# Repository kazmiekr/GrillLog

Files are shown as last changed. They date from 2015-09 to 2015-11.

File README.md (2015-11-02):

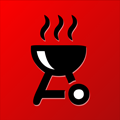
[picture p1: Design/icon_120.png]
 
#GrillLog

This is a project that uses an Arduino UNO to monitor two temperature probes used for a BBQ smoker setup. One probe for food and another for the internal grill temp.  The temperature data is collected by the Arduino, then sent to a proxy server via the SparkFun wifi shield, which is based on the ESP8266.  The proxy server then forwards the temperature data to parse.com as parse.com required HTTPS and the ESP8266 doesn't.  Before the data is saved on Parse, a `beforeSave` trigger fires, and if the temp goes over a certain threshold, it will send a push notification to any subscribed clients.  There is an iOS project in here that allows for simple reading of the parse.com data.

# Project Writeup

View a full writeup of the project at http://www.universalmind.com/smoking-meat-with-the-internet-of-things/

##Parts
* Breadboard 
* Misc Jumper wires
* [Arduino Uno R3](http://www.amazon.com/Arduino-Ultimate-Starter-page-Instruction/dp/B00BT0NDB8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)
* [Sparkfun Wifi Shield](https://www.sparkfun.com/products/13287)
* [Maverick ET732 Smoker Probe](http://www.amazon.com/gp/product/B006XLWL7K?psc=1&redirect=true&ref_=oh_aui_detailpage_o04_s00)
* Generic Food Probe - ( I’m using one from [this](http://www.amazon.com/Oregon-Scientific-AW129-Wireless-Thermometer/dp/B0006G2WYK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))
* 1X 10K Trimpot
* 1X 16x2 LCD Module With Presoldered pinheaders ( Using the one from [this](http://www.amazon.com/gp/product/B00HI0RYJK?psc=1&redirect=true&ref_=oh_aui_detailpage_o06_s00) )
* 1X 220K resistor
* 1X 1M resistor
* 2X [2.5mm jacks](http://www.amazon.com/gp/product/B00AKWR59M?psc=1&redirect=true&ref_=oh_aui_detailpage_o06_s00) soldered to wires

##Diagram
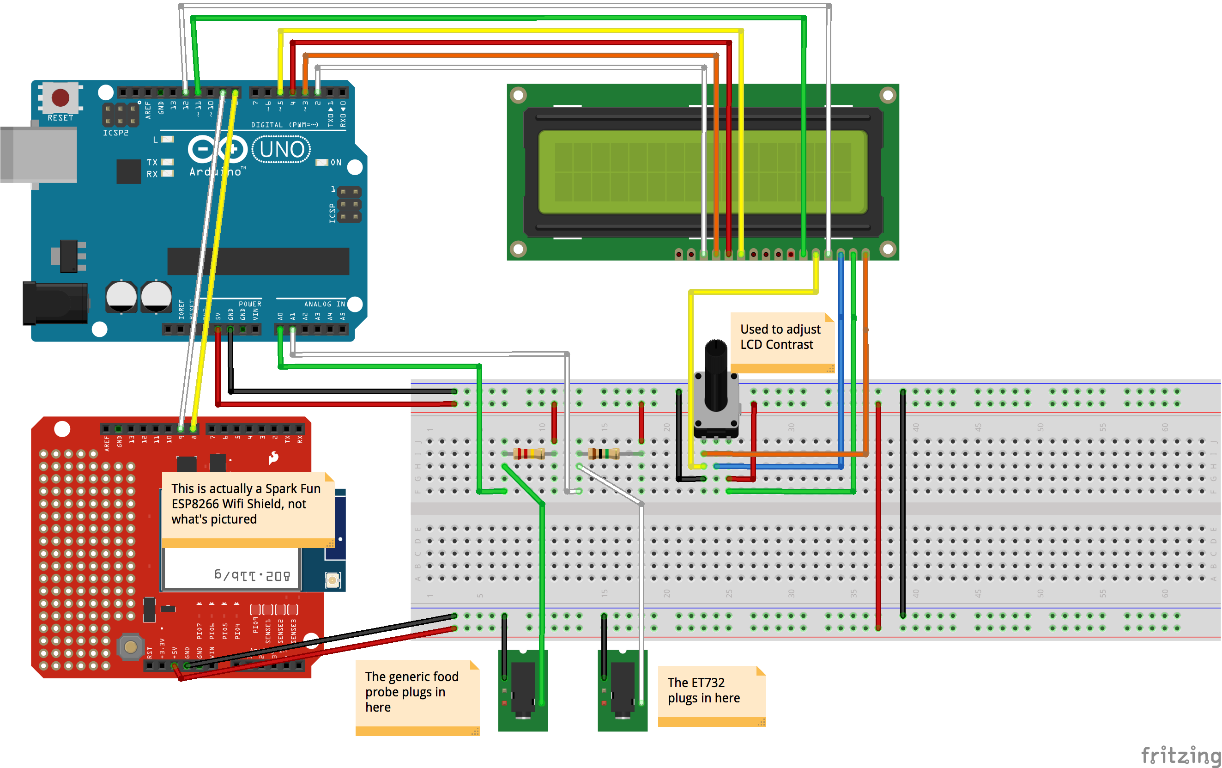
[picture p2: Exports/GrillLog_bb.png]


##Pictures
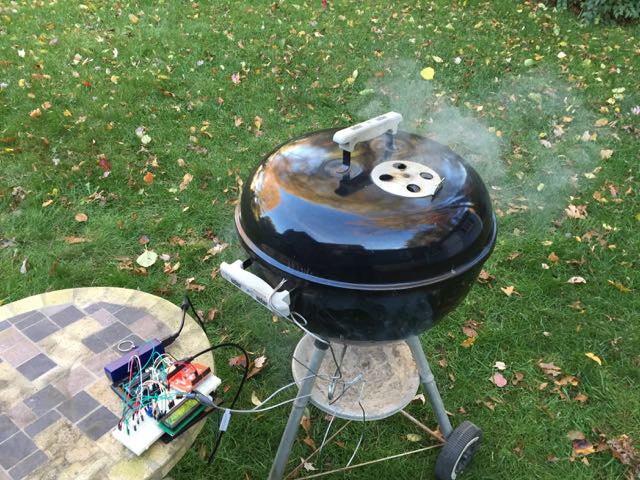
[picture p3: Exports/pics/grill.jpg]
Grill

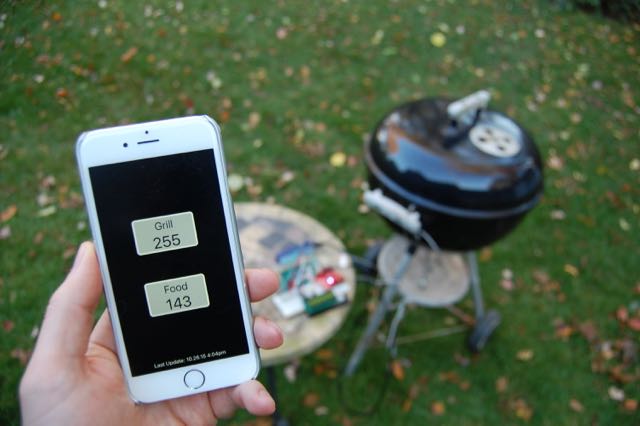
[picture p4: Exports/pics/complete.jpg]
Complete


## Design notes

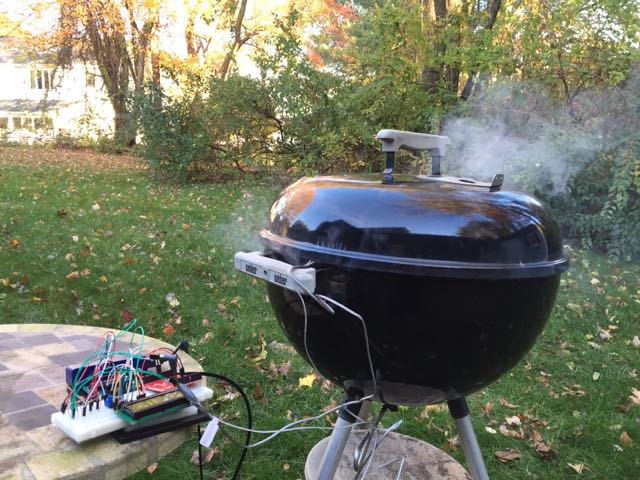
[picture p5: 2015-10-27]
Exports/pics/grill2.jpg

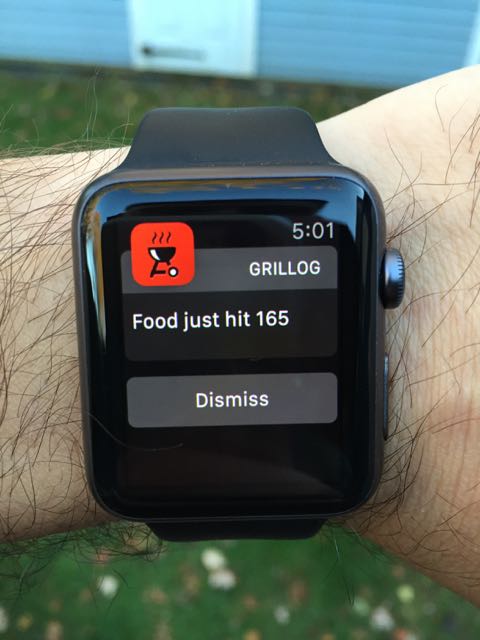
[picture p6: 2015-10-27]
Exports/pics/watch.jpg

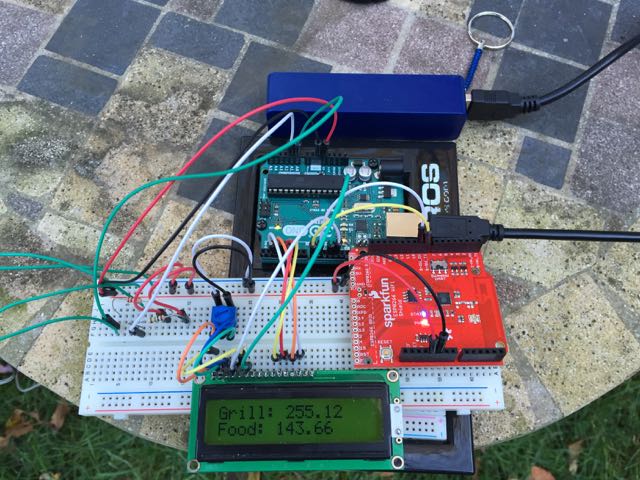
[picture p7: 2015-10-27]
Exports/pics/circuit.jpg

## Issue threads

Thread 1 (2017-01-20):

What is the board the 2.5mm are soldered to?

daleyjem, 2017-01-20:
Maybe I'm missing something, but what is the board that the 2.5mm jacks are soldered to? I think that's key as to why I'm getting all zeros by putting the jack straight into the breadboard.

kazmiekr, 2017-01-24:
Hey Jeremy, the 2.5mm jacks are just soldered to wires and the wires are placed into the breadboard. If you aren't getting any values I'd double check connection points and then maybe check it with a multimeter or something to see if the jack is working. Hope that helps! Let me know if you have any other questions! 🍖

daleyjem, 2017-01-24:
I only see 2 wires though... do you not connect the back terminal of the jack to anything?

kazmiekr, 2017-01-25:
I only use two of the 3 connections, I'm not really sure if that's the best approach or not, but that's how I got it to read values.  It was just a bit of trial an error to figure out which connections worked. Hope that helps!

daleyjem, 2017-02-02:
Ok. Which connections did you use, because I bought the exact same ones you used. The back and left? The left and right?

kazmiekr, 2017-02-06:
Back and the left (see picture), I need to make a better connection on these though because the wires constantly break off and I have to re-solder them, just fyi

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

Closed 2017-01-24.

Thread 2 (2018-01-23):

Readings off

clomas, 2018-01-23:
Hello,

I'm not sure if this is the best way to get in touch but I've attempted to use the source code. I'm using an ET-733 probe and a 1M ohm resistor but my readings are off by a bit. In boiling water my probe reads 184F and in water full of ice cubes it reads 44F. Is there anything I could be doing incorrectly? I'm new to programming for electronics, so apologies if it's something obvious.

Thanks
Clint

kazmiekr, 2018-01-31:
Hey Clint! The calculations I used to convert the resistance to temperature aren't an exact thing unfortunately, I had to mess with the numbers a bit for my specific setup. You can read a bit about what I did on my medium post at https://medium.com/@kazmiekr/smoking-meat-with-the-internet-of-things-b047ecda94a0 or you can just try to mess with the beta coefficients in https://github.com/kazmiekr/GrillLog/blob/master/Arduino/GrillLog/GrillLog.ino#L34 . Not sure if that'll help you or not, but maybe it'll get you in the right direction. My temperatures were never really exact, they fluctuated a bit, but were close enough for me. Anytime the meat got close, I'd double check it with a different meat therm.

clomas, 2018-01-31:
Thanks, I'll give it a go. There a a lot of code examples for the ET73 thermometers online, a lot of people recommend them over the thermometers we're using. Might end up trying them. Thanks again mate.

kazmiekr, 2018-02-02:
Clint, let me know what you end up doing, I'd love to hear how people are actually using this code for things. 🍖 🔥

Closed 2018-01-31.

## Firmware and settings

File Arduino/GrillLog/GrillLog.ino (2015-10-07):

/************************************************************
GrillLog
Kevin Kazmierczak

This sketch will read temperature data from two probes using 
A0 and A1 and will sent that data up to a proxy server using an 
ESP8266 via serial commands. The current temperatures are also 
displayed on a 2 line LCD.

************************************************************/

#include <SoftwareSerial.h>
#include <LiquidCrystal.h>

// External lib config
LiquidCrystal lcd(12, 11, 5, 4, 3, 2);
SoftwareSerial esp8266(8,9);

// Generic config
#define TEMP_READ_DELAY 10000 // 10 seconds between temp reading
#define BAUD_RATE 9600 // Baudrate for serial monitor and ESP

// Proxy Server configs
const char destServer[] = "192.168.1.9";
const uint16_t destPort = 8050;
const String postEndpoint = "/temp";

// Temperature Probes 
#define TEMPERATURENOMINAL 25
#define NUMSAMPLES 10 // Number of samples to smooth input

#define FOOD_PIN 0
#define FOOD_THERMISTORNOMINAL 192000 // resistance at 25 degrees C 
#define FOOD_BCOEFFICIENT 4250 // The beta coefficient of the thermistor
#define FOOD_SERIESRESISTOR 220000 // the value of the 'other' resistor
 
#define GRILL_PIN 1
#define GRILL_THERMISTORNOMINAL 1000000 // resistance at 25 degrees C 
#define GRILL_BCOEFFICIENT 4800 // The beta coefficient of the thermistor
#define GRILL_SERIESRESISTOR 1000000 // the value of the 'other' resistor

// ESP8266 Config
// Lots of this was pulled from https://github.com/sparkfun/SparkFun_ESP8266_AT_Arduino_Library

#define ESP8266_RX_BUFFER_LEN 128 // Number of bytes in the serial receive buffer
char esp8266RxBuffer[ESP8266_RX_BUFFER_LEN];
unsigned int bufferHead; // Holds position of latest byte placed in buffer.

// Define out the AT commands we're going to use to setup the wifi connection and
// send the data
const char ESP8266_OPEN_CONNECTION[] = "AT+CIPSTART";
const char ESP8266_SEND_CONNECTION[] = "AT+CIPSEND";
const char ESP8266_CLOSE_CONNECTION[] = "AT+CIPCLOSE";
const char ESP8266_CHANGE_MUX[] = "AT+CIPMUX";
// What to look for to know the previous command was sent correctly
const char RESPONSE_OK[] = "OK\r\n";

const int DEFAULT_TIMEOUT = 5000; // Timeout for an AT command before we call it a failure
const int SEND_COMMAND_DELAY = 100; // Just a delay between AT commands to help avoid issues

const boolean debugMode = false; // Enable this to see all the AT commands and responses happening in the monitor

float samples[NUMSAMPLES];

void setup() {
  Serial.begin(BAUD_RATE);
  esp8266.begin(BAUD_RATE);
  lcd.begin(16, 2);
}

void loop() {

  // ** General flow ** 
  // 1) Get analog reading from pin
  // 2) Convert the analog input to resistance
  // 3) Calculate degrees C from the resistance
  // 4) Convert that to F
  // 5) Write those values to lcd
  // 6) Send them to a server
  // 7) Wait x seconds and repeat

  float foodAverage = sampleTempData(FOOD_PIN, NUMSAMPLES);
  float foodResistance = convertAnalogToResistance(foodAverage, FOOD_SERIESRESISTOR);
  float foodDegC = calculateCFromResistance(foodResistance, FOOD_THERMISTORNOMINAL, FOOD_BCOEFFICIENT, TEMPERATURENOMINAL);
  float foodDegF = convertCtoF(foodDegC);

  float grillAverage = sampleTempData(GRILL_PIN, NUMSAMPLES);
  float grillResistance = convertAnalogToResistance(grillAverage, GRILL_SERIESRESISTOR);
  float grillDegC = calculateCFromResistance(grillResistance, GRILL_THERMISTORNOMINAL, GRILL_BCOEFFICIENT, TEMPERATURENOMINAL);
  float grillDegF = convertCtoF(grillDegC);

  // Update temps on display
  writeTempDatatoSerial(grillDegF, foodDegF);
  writeTempToDisplay(grillDegF, foodDegF);

  // Send those two temps to your server of choice
  sendDataToServer(grillDegF, foodDegF);
  
  Serial.println("--------------");
  
  delay(TEMP_READ_DELAY);
}

/**
 * Samples the analog input numSamples number of times to smooth out the final value
 */
float sampleTempData(int pin, int numSamples){
  uint8_t i;
  float average;
 
  // take N samples in a row, with a slight delay
  for (i=0; i< numSamples; i++) {
   samples[i] = analogRead(pin);
   delay(10);
  }
 
  // average all the samples out
  average = 0;
  for (i=0; i< numSamples; i++) {
     average += samples[i];
  }
  average /= numSamples;

  Serial.print("Average analog reading "); 
  Serial.println(average);

  return average;
}

/**
 * Helper method to convert analog data to resistance. Taken from https://learn.adafruit.com/thermistor/using-a-thermistor
 */
float convertAnalogToResistance(float avg, long resistor){
  avg = 1023 / avg - 1;
  avg = resistor / avg;
  Serial.print("Thermistor resistance "); 
  Serial.println(avg);
  return avg;
}

/**
 * Helper method to calculate C from a resistance. This taken from https://learn.adafruit.com/thermistor/using-a-thermistor
 */
float calculateCFromResistance(float resistance, long thermNominal, int coefficient, int tempNominal){
  float steinhart;
  steinhart = resistance / thermNominal;     // (R/Ro)
  steinhart = log(steinhart);                  // ln(R/Ro)
  steinhart /= coefficient;                   // 1/B * ln(R/Ro)
  steinhart += 1.0 / (tempNominal + 273.15); // + (1/To)
  steinhart = 1.0 / steinhart;                 // Invert
  steinhart -= 273.15;                         // convert to C
  return steinhart;
}

/**
 * Converts C to F
 */
float convertCtoF(float degC){
  return degC * (9.0/5.0) + 32.0;
}

/**
 * Log the temps to the serial monitor
 */
void writeTempDatatoSerial(float temp1, float temp2){
  Serial.print("Grill: "); 
  Serial.println(temp1, 2);
  Serial.print("Food: ");
  Serial.println(temp2, 2);
}

/**
 * Log the temps to the LCD Display
 */
void writeTempToDisplay(float temp1, float temp2){
  lcd.setCursor(0, 0);
  lcd.print("Grill: ");
  lcd.print(temp1, 2);
  lcd.print(" ");
  lcd.setCursor(0, 1);
  lcd.print("Food: ");
  lcd.print(temp2, 2);
  lcd.print(" ");
}

/**
 * Sends the two temps to the server you've defined.  They get
 * POST'd as:
 *  'foodTemp=100.0&grillTemp=250.0
 */
void sendDataToServer(float grillTemp, float foodTemp){
  
  // Construct POST headers
  String httpPost = "POST " + postEndpoint + " HTTP/1.1\r\n";
  httpPost += "Host: " + String(destServer) + "\r\n";
  httpPost += "Content-Type: application/x-www-form-urlencoded\r\n";
  httpPost += "Connection: close\r\n";
  
  // Construct POST Data
  String params = "foodTemp=" + String(foodTemp) + "&grillTemp=" + String(grillTemp);
  String contentLength = "Content-Length: " + String(params.length()) + "\r\n\r\n";
  // Combine them
  httpPost += contentLength + params;

  // Ensure we're in single connection mode.  The ESP supports multi connections, but for simplicity's sake
  // we're going to stay serial here and only do one connection at a time
  sendCommand(ESP8266_CHANGE_MUX, "0");
  int resp = readForResponse(RESPONSE_OK, DEFAULT_TIMEOUT);

  delay(SEND_COMMAND_DELAY); // Pause between commands

  // Open connection to proxy server
  String connection = "\"TCP\",\"" + String(destServer) + "\"," + String(destPort);
  char buf[connection.length()+1];
  connection.toCharArray(buf, connection.length() + 1);
  sendCommand(ESP8266_OPEN_CONNECTION, buf);
  resp = readForResponse(RESPONSE_OK, DEFAULT_TIMEOUT);
  
  delay(SEND_COMMAND_DELAY);

  // Tell the ESP how much data we're about to send it
  String postLength = String(httpPost.length());
  char charBuf[postLength.length()+2];
  postLength.toCharArray(charBuf, postLength.length()+2);
  
  sendCommand(ESP8266_SEND_CONNECTION, charBuf);
  resp = readForResponse(">", DEFAULT_TIMEOUT);
  
  delay(SEND_COMMAND_DELAY);

  // Once we get the '>', we're ready to send out character buffer to the ESP
  esp8266.print(httpPost);

  // Wait for an OK and we're good!
  resp = readForResponse("200 OK", DEFAULT_TIMEOUT);
  
  if (resp > 0){
    Serial.println("Saved temp to server");
  }
}

/**
 * Wrapper method to support sendCommand without params
 */
void sendCommand(const char * cmd){
  sendCommand(cmd, NULL);
}

/**
 * Sends an AT command with params over the software serial
 */
void sendCommand(const char * cmd, const char * params){
  if (debugMode){
    Serial.println("SENDING:" + String(cmd) + ", PARAMS: " + String(params));  
  }
  esp8266.print(cmd);
  if (params){
    esp8266.print("=");
    esp8266.print(params);
  }
  esp8266.print("\r\n");
}

/**
 * Waits to receive a response on the software serial.  If the response is found, it'll
 * return the count of received data.  Heavily borrowed from https://github.com/sparkfun/SparkFun_ESP8266_AT_Arduino_Library
 */
int16_t readForResponse(const char * rsp, unsigned int timeout){
  unsigned long timeIn = millis();  // Timestamp coming into function
  unsigned int received = 0; // received keeps track of number of chars read
  
  clearBuffer();  // Clear the class receive buffer (esp8266RxBuffer)
  while (timeIn + timeout > millis()){
    // If data is available on UART RX
    if (esp8266.available()) {
      received += readByteToBuffer();
      if (searchBuffer(rsp)){
        if (debugMode){
          logATResponse(received);
        }
        return received;  // Return how number of chars read 
      }
    }
  }

  int16_t errorCode;
  if (received > 0) // If we received any characters
    errorCode = -2; // Return unkown response error code
  else // If we haven't received any characters
    errorCode = -1; // Return the timeout error code
    
  logATResponse(errorCode);
  return errorCode;
}

/**
 * Logs detail around the AT command to the serial monitor
 */
void logATResponse(int resp){
  if (resp > 0){
    Serial.println("AT COMMAND OK");
    Serial.println("****");
    Serial.println(esp8266RxBuffer);
    Serial.println("****");
  } else {
    Serial.println("AT COMMAND FAILED WITH CODE: " + String(resp));
    Serial.println("****");
    Serial.println(esp8266RxBuffer);
    Serial.println("****");
  }
}

/**
 * Helper method to convert an int to a char *
 */
char * convertToString(int val){
  String s = String(val);
  Serial.println("S:" + s);
  int strlen = s.length();
  Serial.println("l:" + String(strlen));
  char buf[strlen+1]; // Include null thing
  s.toCharArray(buf, strlen+1);
  Serial.println("buf:" + String(buf));
  return buf;
}

/**
 * Clears the ESP buffer. Taken from https://github.com/sparkfun/SparkFun_ESP8266_AT_Arduino_Library
 */
void clearBuffer(){
  memset(esp8266RxBuffer, '\0', ESP8266_RX_BUFFER_LEN);
  bufferHead = 0;
}

/**
 * Reads the ESP data. Taken from https://github.com/sparkfun/SparkFun_ESP8266_AT_Arduino_Library
 */
unsigned int readByteToBuffer(){
  // Read the data in
  char c = esp8266.read();
  
  // Store the data in the buffer
  esp8266RxBuffer[bufferHead] = c;
  //! TODO: Don't care if we overflow. Should we? Set a flag or something?
  bufferHead = (bufferHead + 1) % ESP8266_RX_BUFFER_LEN;
  
  return 1;
}

/**
 * Searches the string buffer for a specific string to be found. Typically so we know the response
 * was OK
 */
char * searchBuffer(const char * test){
  int bufferLen = strlen((const char *)esp8266RxBuffer);
  // If our buffer isn't full, just do an strstr
  if (bufferLen < ESP8266_RX_BUFFER_LEN){
    return strstr((const char *)esp8266RxBuffer, test);
  } else { //! TODO
    // If the buffer is full, we need to search from the end of the 
    // buffer back to the beginning.
    int testLen = strlen(test);
    for (int i=0; i<ESP8266_RX_BUFFER_LEN; i++){
      
    }
  }
}

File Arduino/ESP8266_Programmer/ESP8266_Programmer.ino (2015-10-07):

/************************************************************
ESP8266_Programmer
Kevin Kazmierczak

This is a simple sketch to supply some defaults for network configuration
into the ESP8266 on the SparkFun Wifi Shield using the Arduino as a serial passthrough.  
Anything you type into the serial monitor will get sent to the ESP8266 and any response it 
has will get received in the monitor.

MAKE SURE YOU SET THE SERIAL MONITOR TO USE 'BOTH NL&CR' LINE ENDINGS or the stuff you enter here
will not get sent!

To configure your ESP8266, you can enter some AT commands.  Details can be found online or somewhere 
like - https://cdn.sparkfun.com/assets/learn_tutorials/4/0/3/4A-ESP8266__AT_Instruction_Set__EN_v0.30.pdf 
depending on the version of the firmware installed on the chip

Examples
AT - Status check
AT+GMR - Show version information
AT+CWLAP - List access points
AT+CIFSR - Get IP address
AT+CWJAP_DEF="SSID","PASSWORD" - Connects to access point and saves as default
AT+CWQAP - Disconnect from AP
AT+PING="www.kevinkaz.com" - Ping an address

I typically use to check on the running config and ensure the chip is 
default connecting to my wifi so I don't need to program around that portion.

You may need to mess with the baud_rates depending on what your ESP is running at.  By
default the SparkFun shield is using 9600.  Also make sure you set your Serial Monitor to 
use the number you set here

************************************************************/

#include <SoftwareSerial.h>

SoftwareSerial esp8266(8,9);

void setup() 
{
  Serial.begin(9600);
  esp8266.begin(9600);
}

void loop() 
{
  serialPassthrough();
}

void serialPassthrough()
{
  while (Serial.available())
    esp8266.write(Serial.read());
  while (esp8266.available())
    Serial.write(esp8266.read());
}

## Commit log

2015-09-28 Initial commit of arduino/proxy code
    [GrillLog.fzz]
2015-09-28 Adds in logs of probe resistances
    [probe_temps.xlsx]
2015-10-07 Updated Fritzing doc
    [GrillLog.fzz]
2016-02-25 Adds in Alexa sample code
